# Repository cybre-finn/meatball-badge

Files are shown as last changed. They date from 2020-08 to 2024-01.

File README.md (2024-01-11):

# Meatball Badge

Wear the NASA meatball logo as a PCB lanyard badge.

Features:
- illuminated vector and stars (reverse mounted LEDs)
- programmable via Arduino IDE
- ESP32 MCU
- USB Type C interface
- Li-ion battery

For (interactive) BOM see the [Instructions page](https://cybre-finn.github.io/meatball-badge/) (german).

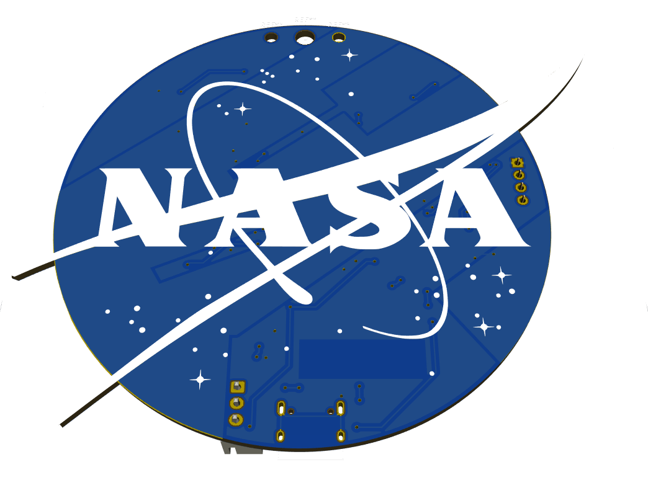
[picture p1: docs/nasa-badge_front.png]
front render


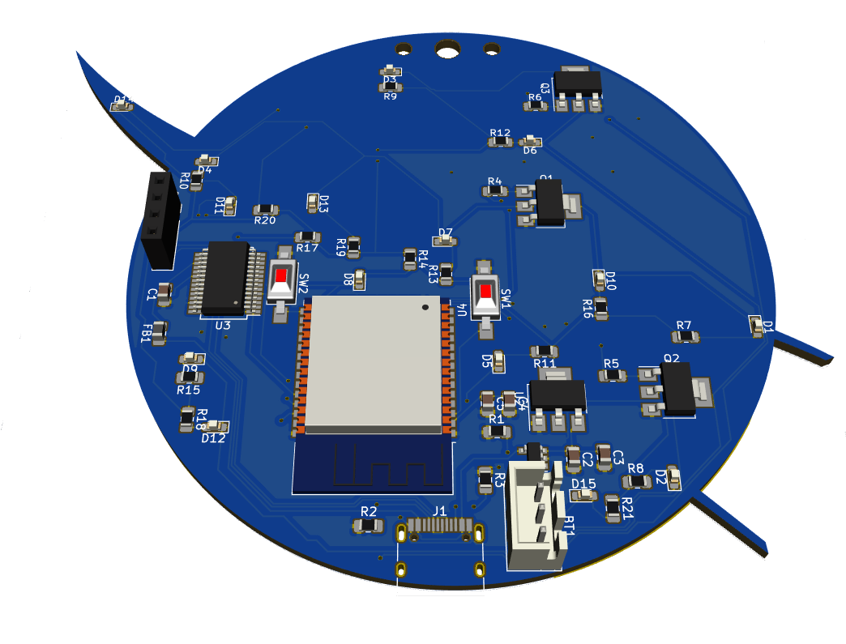
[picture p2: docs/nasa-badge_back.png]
back render


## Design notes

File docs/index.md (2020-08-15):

Das meatball-badge ist ein PCB-Badge in Form des Nasa-Meatball-Logos.



Den Abschnitt "Zusammenbau" vor Beginn bitte komplett durchlesen.

## Zusammenbau
Das meatball-badge ist ein SMD-Lötworkshop. SMD/SMT steht für "Surface Mounted Device" oder "Surface Mounted Technology". Im Gegensatz zu THT "Through Hole Technology" werden die Bauteile nicht durch Löcher auf der Platine gesteckt, sondern auf der Platine befestigt.
Dadurch wird der benötigte Platz reduziert und die Bauteile können maschinell durch sogenannte [Pick-and-Place-Maschinen](https://en.wikipedia.org/wiki/Pick-and-place_machine) und [Reflow-Öfen](https://en.wikipedia.org/wiki/Reflow_soldering) befestigt werden.
Das händische Löten von SMD kann zuerst etwas schwierig sein und erfordert etwas Übung. Die auf diesem Badge verwendeten Bauteile sind allerdings bis auf die LEDs etwas größere SMD-Varianten. 

pic of pcb with parts on top

Wenn man das noch nie gemacht hat, dann gibts hier eine [Anleitung in Comic-Form](http://mightyohm.com/files/SMT_Soldering_Its_Easier_Than_You_Think_EN.pdf).

### Kathoden- und Annodenseite der LEDs
Da die SMD-LEDs keine unterschiedlichen Beinlängen haben, wird die Polarität der LED durch einen Aufdruck bestimmt. Bei unseren LEDs ist das ein T-Förmiger aufdruck.
```
Kathode(-)
   T
Annode(+)
```

### LED-Hack
Die SMD-LEDs beleuchten den roten Vektor und die 5 Sterne von hinten. Dafür müssen die LEDs umgedreht aufgelötet werden. Also so, dass die Beschriftung sichtbar ist. Das ist eigentlich nicht die gedachte Anwendung dieser dieser LEDs. Aufgrund der Form könnte das etwas schwieriger werden. Daher sind ein paar mehr LEDs beigelegt.

### Butter bei die Fische
Ganz praktisch ist das iBOM-Tool. Damit kann interaktiv die Bestückung im Browser durchgegangen werden. Es empfiehlt sich, das Tool auf einem grösseren Display aufzurufen.

[IBOM](ibom)

Nicht vergessen: Die LEDs müssen gedreht werden.

### Sichterheitshinweis
Diesem Badge liegt eine Lithium-Batterie bei. Es ist unbedingt darauf zu achten, dass die Kontakte nicht kurzgeschlossen werden und die Batterie niemals beschädigt wird. Die Nutzung geschieht auf eigene Verantwortung.

## Erstes Programm
Alle drei LED-Arrays and den Transistoren blinken.

```{C}
int LED_RED_1 = 19;
int LED_RED_2 = 21;
int LED_WHITE = 22;
void setup() {
pinMode (LED_RED_1, OUTPUT);
pinMode (LED_RED_2, OUTPUT);
pinMode (LED_WHITE, OUTPUT);
}
void loop() {
digitalWrite(LED_RED_1, HIGH);
digitalWrite(LED_RED_2, HIGH);
digitalWrite(LED_WHITE, HIGH);
delay(1000);
digitalWrite(LED_RED_1, LOW);
digitalWrite(LED_RED_2, LOW);
digitalWrite(LED_WHITE, LOW);
delay(1000);
}
```

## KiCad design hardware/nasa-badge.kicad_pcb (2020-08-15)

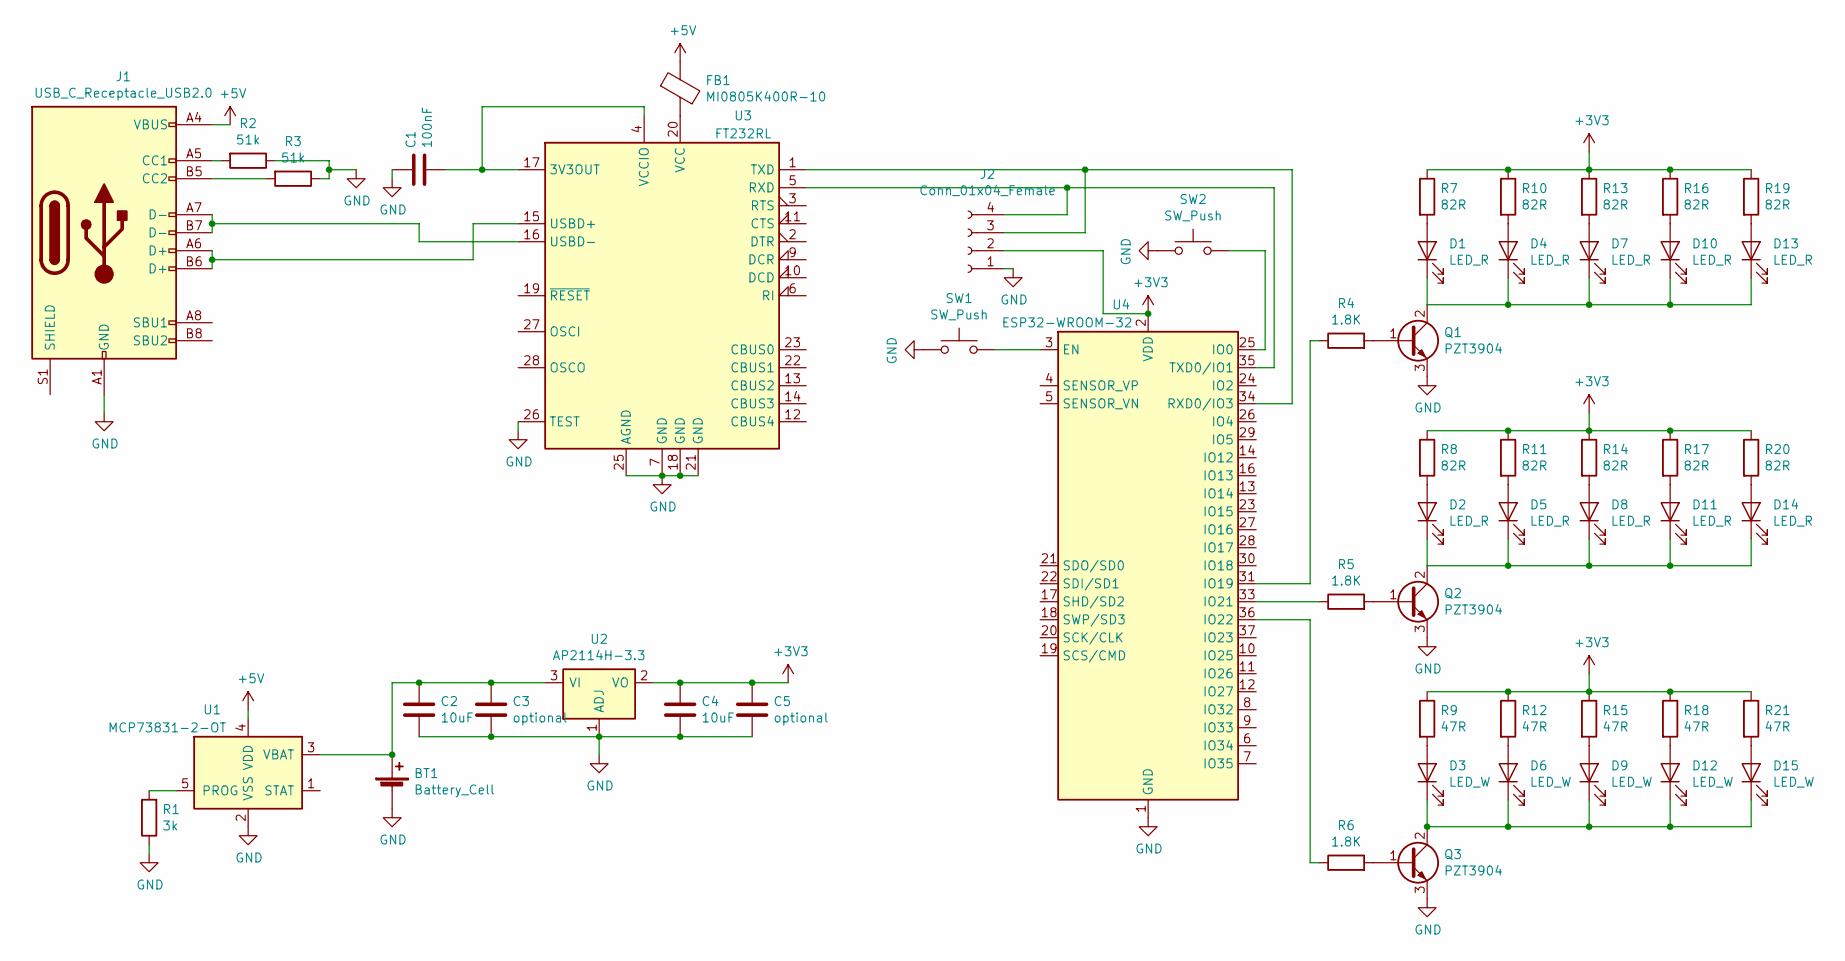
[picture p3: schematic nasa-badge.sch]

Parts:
BT1: Battery_Cell; JST_XH_B3B-XH-A_1x03_P2.50mm_Vertical
C1: 100nF; C_0805_2012Metric_Pad1.15x1.40mm_HandSolder
C2, C4: 10uF; C_0805_2012Metric_Pad1.15x1.40mm_HandSolder
C3, C5: optional; C_0805_2012Metric_Pad1.15x1.40mm_HandSolder
D1, D2, D4, D5, D7, D8, D10, D11, D13, D14: LED_R; LED_0603_1608Metric_Pad1.05x0.95mm_HandSolder
D3, D6, D9, D12, D15: LED_W; LED_0603_1608Metric_Pad1.05x0.95mm_HandSolder
FB1: MI0805K400R-10; L_0805_2012Metric_Pad1.15x1.40mm_HandSolder
J1: USB_C_Receptacle_USB2.0; USB_C_Receptacle_HRO_TYPE-C-31-M-12
J2: Conn_01x04_Female; PinSocket_1x04_P2.54mm_Vertical
Q1, Q2, Q3: PZT3904; SOT-223
R1: 3k; R_0805_2012Metric_Pad1.15x1.40mm_HandSolder
R2, R3: 51k; R_0805_2012Metric_Pad1.15x1.40mm_HandSolder
R4, R5, R6: 1.8K; R_0805_2012Metric_Pad1.15x1.40mm_HandSolder
R7, R8, R10, R11, R13, R14, R16, R17, R19, R20: 82R; R_0805_2012Metric_Pad1.15x1.40mm_HandSolder
R9, R12, R15, R18, R21: 47R; R_0805_2012Metric_Pad1.15x1.40mm_HandSolder
SW1, SW2: SW_Push; SW_SPST_FSMSM
U1: MCP73831-2-OT; SOT-23-5
U2: AP2114H-3.3; SOT-223-3_TabPin2
U3: FT232RL; SSOP-28_5.3x10.2mm_P0.65mm
U4: ESP32-WROOM-32

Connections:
+3V3: C4.1, C5.1, J2.2, R7.1, R8.1, R9.1, R10.1, R11.1, R12.1, R13.1, R14.1, R15.1, R16.1, R17.1, R18.1, R19.1, R20.1, R21.1, U2.2 (VO), U4.2 (VDD)
+5V: FB1.1, J1.A4 (VBUS), J1.A9 (VBUS), J1.B4 (VBUS), J1.B9 (VBUS), U1.4 (VDD)
GND: BT1.2 (-), C1.1, C2.2, C3.2, C4.2, C5.2, J1.A1 (GND), J1.A12 (GND), J1.B1 (GND), J1.B12 (GND), J2.1, Q1.3 (E), Q2.3 (E), Q3.3 (E), R1.1, R2.1, R3.1, SW1.1, SW2.1, U1.2 (VSS), U2.1 (ADJ), U3.7 (GND), U3.18 (GND), U3.21 (GND), U3.25 (AGND), U3.26 (TEST), U4.1 (GND), U4.15 (GND), U4.38 (GND), U4.39 (GND)
unnamed: BT1.1 (+), C2.1, C3.1, U1.3 (VBAT), U2.3 (VI)
unnamed: C1.2, U3.4 (VCCIO), U3.17 (3V3OUT)
unnamed: D1.1 (K), D4.1 (K), D7.1 (K), D10.1 (K), D13.1 (K), Q1.2 (C), Q1.4 (C)
unnamed: D1.2 (A), R7.2
unnamed: D2.2 (A), R8.2
unnamed: D3.2 (A), R9.2
unnamed: D4.2 (A), R10.2
unnamed: D5.2 (A), R11.2
unnamed: D6.2 (A), R12.2
unnamed: D7.2 (A), R13.2
unnamed: D8.2 (A), R14.2
unnamed: D9.2 (A), R15.2
unnamed: D10.2 (A), R16.2
unnamed: D2.1 (K), D5.1 (K), D8.1 (K), D11.1 (K), D14.1 (K), Q2.2 (C), Q2.4 (C)
unnamed: D11.2 (A), R17.2
unnamed: D3.1 (K), D6.1 (K), D9.1 (K), D12.1 (K), D15.1 (K), Q3.2 (C), Q3.4 (C)
unnamed: D12.2 (A), R18.2
unnamed: D13.2 (A), R19.2
unnamed: D14.2 (A), R20.2
unnamed: D15.2 (A), R21.2
unnamed: FB1.2, U3.20 (VCC)
unnamed: J1.A5 (CC1), R2.2
unnamed: J1.A6 (D+), J1.B6 (D+), U3.15 (USBD+)
unnamed: J1.A7 (D-), J1.B7 (D-), U3.16 (USBD-)
unnamed: J1.B5 (CC2), R3.2
unnamed: J2.3, U3.1 (TXD), U4.34 (RXD0/IO3)
unnamed: J2.4, U3.5 (RXD), U4.35 (TXD0/IO1)
unnamed: Q1.1 (B), R4.2
unnamed: Q2.1 (B), R5.2
unnamed: Q3.1 (B), R6.2
unnamed: R1.2, U1.5 (PROG)
unnamed: R4.1, U4.31 (IO19)
unnamed: R5.1, U4.33 (IO21)
unnamed: R6.1, U4.36 (IO22)
unnamed: SW1.2, U4.3 (EN)
unnamed: SW2.2, U4.25 (IO0)

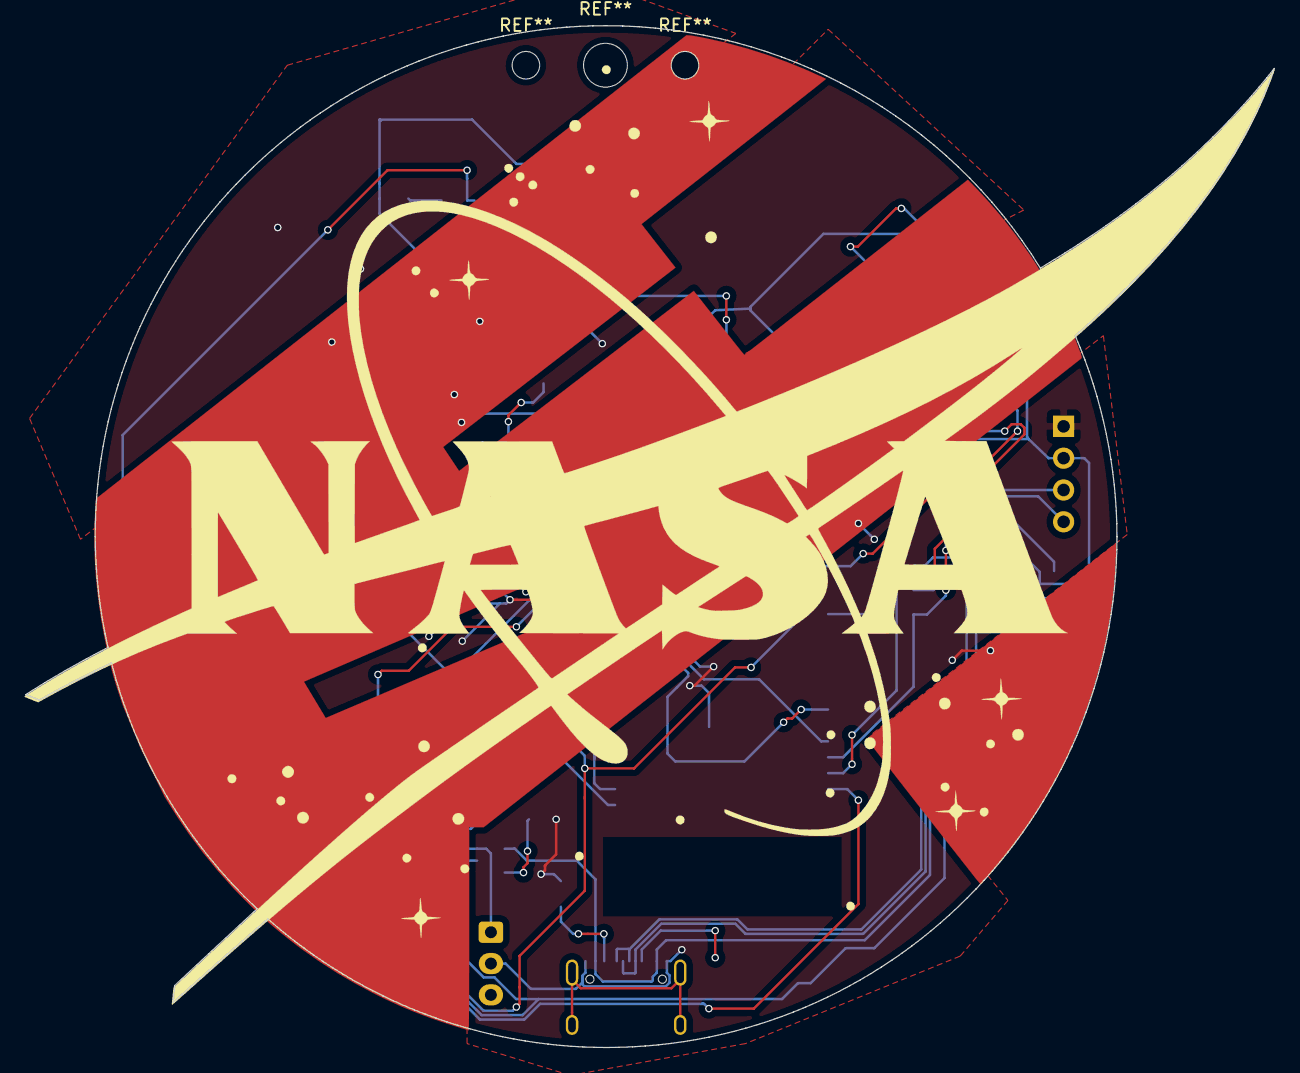
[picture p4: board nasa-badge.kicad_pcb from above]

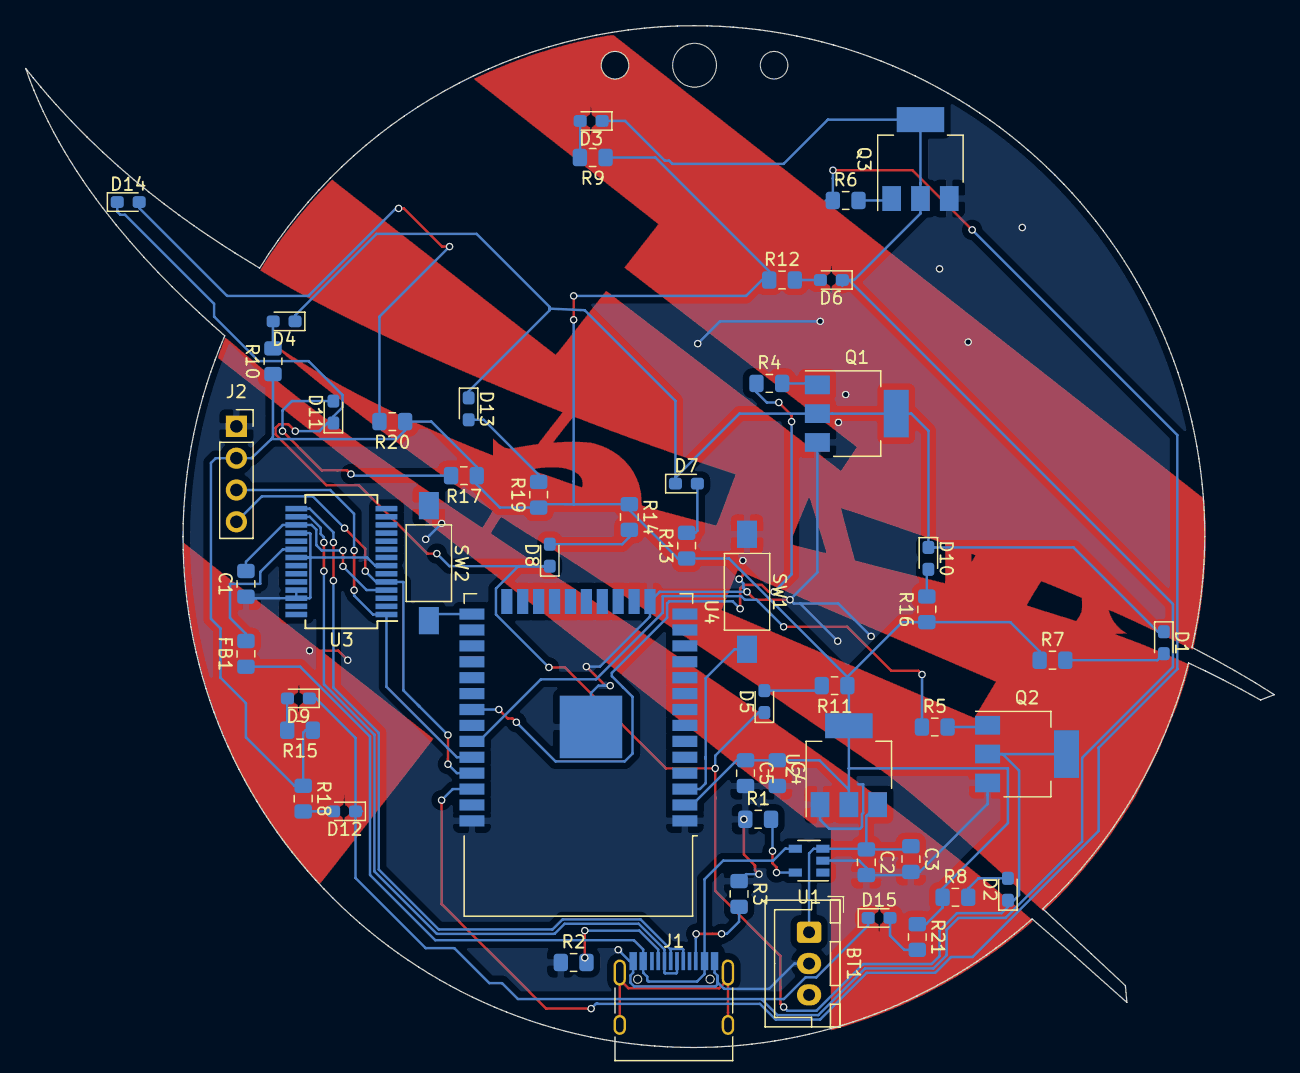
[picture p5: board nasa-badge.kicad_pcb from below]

Board: 2 copper layers, 99.7 x 81.6 mm, 54 parts (54 on the bottom side), 39 nets.

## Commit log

2020-08-14 rev 0.2
    [nasa-badge.kicad_pcb, nasa-badge.sch]
2020-08-14 subdirectory for hardware
    [nasa-badge.kicad_pcb, nasa-badge.sch]
2020-08-15 add board version number
    [nasa-badge.kicad_pcb]
